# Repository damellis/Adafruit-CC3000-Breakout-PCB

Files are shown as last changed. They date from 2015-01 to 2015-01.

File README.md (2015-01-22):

Derivative of the Adafruit CC3000 Breakout PCB
==============================================
This is a derivative of the PCB for the Adafruit CC3000 WiFi Breakout. It adds an ATmega1284 and associated circuitry.

# Original Text Follows

This is the PCB for the Adafruit CC3000 WiFi Breakout
Format is EagleCAD schematic and board layout

For more details, check out the product page at

-----> http://www.adafruit.com/products/1510
-----> http://www.adafruit.com/products/1469

Adafruit invests time and resources providing this open source design, 
please support Adafruit and open-source hardware by purchasing 
products from Adafruit!

Designed by Adafruit Industries.  
Creative Commons Attribution, Share-Alike license, check license.txt for more information
All text above must be included in any redistribution

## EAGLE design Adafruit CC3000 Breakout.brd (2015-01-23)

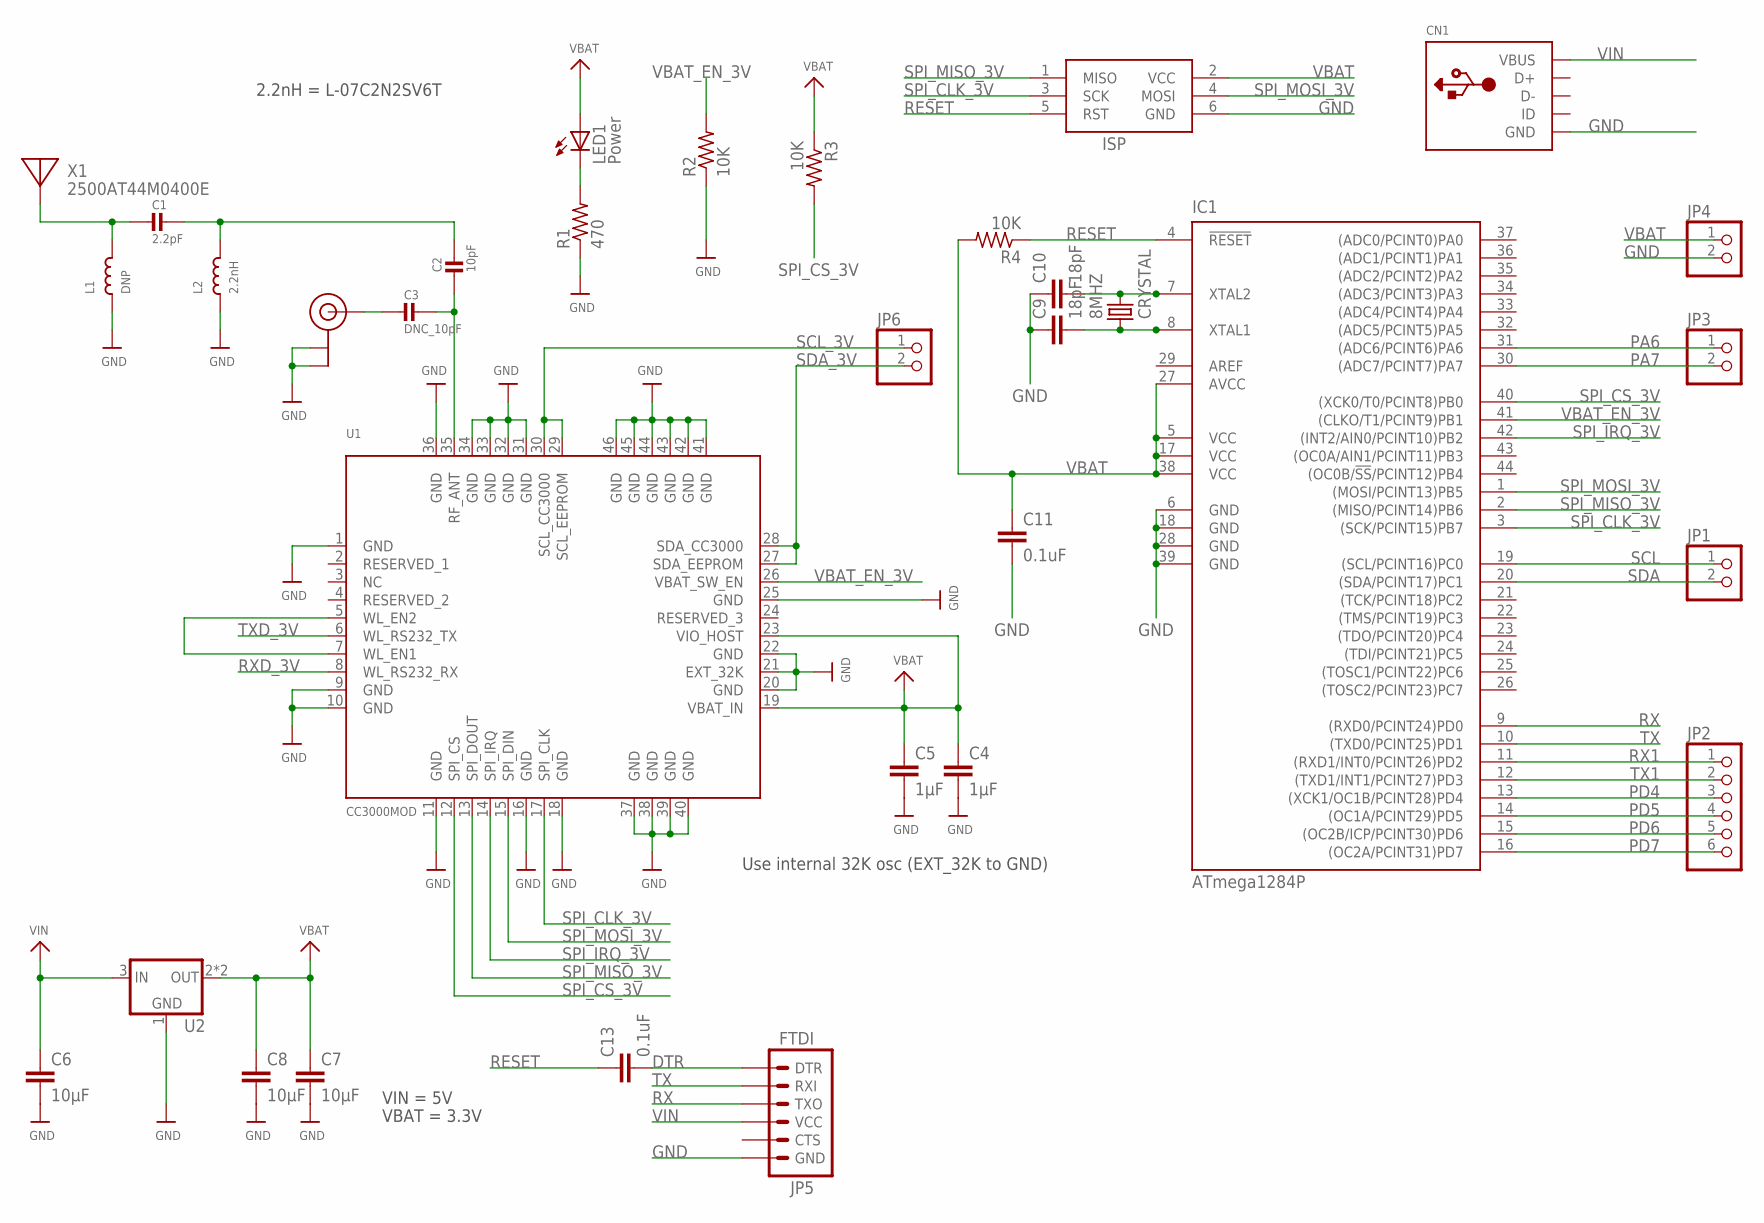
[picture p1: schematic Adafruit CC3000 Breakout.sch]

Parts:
8MHZ: CRYSTAL; 2-SMD-5X3MM
C1: 2.2pF; _0402
C2: 10pF; _0402
C3: DNC_10pF; _0402
C4, C5: 1µF; C1206
C6, C7, C8: 10µF; C1206
C9, C10: 18pF; C1206
C11, C13: 0.1uF; C1206
CN1: USBPWR; USB-MINIB-POWER
IC1: ATmega1284P; TQFP44
ISP: AVRISP-6; AVRISP
JP1, JP3, JP4, JP6: PINHD-1X2; 1X02
JP2: PINHD-1X6; 1X06
JP5: FTDI; 1X06
L1: DNP; _0402
L2: 2.2nH; _0402
LED1: Power; 1206
R1: 470; R1206
R2, R3, R4: 10K; R1206
U1: CC3000MOD
U2: VREG_SOT223; SOT223-R
U$35: U.FL
X1: 2500AT44M0400E; ANT_2500AT44M0400

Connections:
AREF: IC1.29 (AREF)
DTR: C13.2, JP5.DTR
GND: C4.2, C5.2, C6.2, C7.2, C8.2, C9.1, C10.1, C11.2, CN1.GND, IC1.6 (GND), IC1.18 (GND), IC1.28 (GND), IC1.39 (GND), ISP.6 (GND), JP4.2, JP5.GND, L1.1, L2.1, R1.1, R2.1, U1.1 (GND), U1.9 (GND), U1.10 (GND), U1.11 (GND), U1.16 (GND), U1.18 (GND), U1.20 (GND), U1.21 (EXT_32K), U1.22 (GND), U1.25 (GND), U1.31 (GND), U1.32 (GND), U1.33 (GND), U1.34 (GND), U1.36 (GND), U1.37 (GND), U1.38 (GND), U1.39 (GND), U1.40 (GND), U1.41 (GND), U1.42 (GND), U1.43 (GND), U1.44 (GND), U1.45 (GND), U1.46 (GND), U2.1 (GND), U$35.P$1 (GND), U$35.P$2 (GND)
unnamed: C1.2, L1.2, X1.FEED
unnamed: C1.1, C2.1, L2.2
unnamed: C3.2, U$35.P$3 (SIGNAL)
unnamed: C2.2, C3.1, U1.35 (RF_ANT)
unnamed: U1.5 (WL_EN2), U1.7 (WL_EN1)
unnamed: LED1.C, R1.2
unnamed: 8MHZ.P$2 (2), C10.2, IC1.7 (XTAL2)
unnamed: 8MHZ.P$1 (1), C9.2, IC1.8 (XTAL1)
PA6: IC1.31 ((ADC6/PCINT6)PA6), JP3.1
PA7: IC1.30 ((ADC7/PCINT7)PA7), JP3.2
PD4: IC1.13 ((XCK1/OC1B/PCINT28)PD4), JP2.3
PD5: IC1.14 ((OC1A/PCINT29)PD5), JP2.4
PD6: IC1.15 ((OC2B/ICP/PCINT30)PD6), JP2.5
PD7: IC1.16 ((OC2A/PCINT31)PD7), JP2.6
RESET: C13.1, IC1.4 (!RESET), ISP.5 (RST), R4.1
RX: IC1.9 ((RXD0/PCINT24)PD0), JP5.TXO
RX1: IC1.11 ((RXD1/INT0/PCINT26)PD2), JP2.1
RXD_3V: U1.8 (WL_RS232_RX)
SCL: IC1.19 ((SCL/PCINT16)PC0), JP1.1
SCL_3V: JP6.1, U1.29 (SCL_EEPROM), U1.30 (SCL_CC3000)
SDA: IC1.20 ((SDA/PCINT17)PC1), JP1.2
SDA_3V: JP6.2, U1.27 (SDA_EEPROM), U1.28 (SDA_CC3000)
SPI_CLK_3V: IC1.3 ((SCK/PCINT15)PB7), ISP.3 (SCK), U1.17 (SPI_CLK)
SPI_CS_3V: IC1.40 ((XCK0/T0/PCINT8)PB0), R3.2, U1.12 (SPI_CS)
SPI_IRQ_3V: IC1.42 ((INT2/AIN0/PCINT10)PB2), U1.14 (SPI_IRQ)
SPI_MISO_3V: IC1.2 ((MISO/PCINT14)PB6), ISP.1 (MISO), U1.13 (SPI_DOUT)
SPI_MOSI_3V: IC1.1 ((MOSI/PCINT13)PB5), ISP.4 (MOSI), U1.15 (SPI_DIN)
TX: IC1.10 ((TXD0/PCINT25)PD1), JP5.RXI
TX1: IC1.12 ((TXD1/INT1/PCINT27)PD3), JP2.2
TXD_3V: U1.6 (WL_RS232_TX)
VBAT: C4.1, C5.1, C7.1, C8.1, C11.1, IC1.5 (VCC), IC1.17 (VCC), IC1.27 (AVCC), IC1.38 (VCC), ISP.2 (VCC), JP4.1, LED1.A, R3.1, R4.2, U1.19 (VBAT_IN), U1.23 (VIO_HOST), U2.2 (OUT), U2.4 (OUT)
VBAT_EN_3V: IC1.41 ((CLKO/T1/PCINT9)PB1), R2.2, U1.26 (VBAT_SW_EN)
VIN: C6.1, CN1.VBUS, JP5.VCC, U2.3 (IN)

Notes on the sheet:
Use internal 32K osc (EXT_32K to GND)
VIN = 5V
VBAT = 3.3V
2.2nH = L-07C2N2SV6T

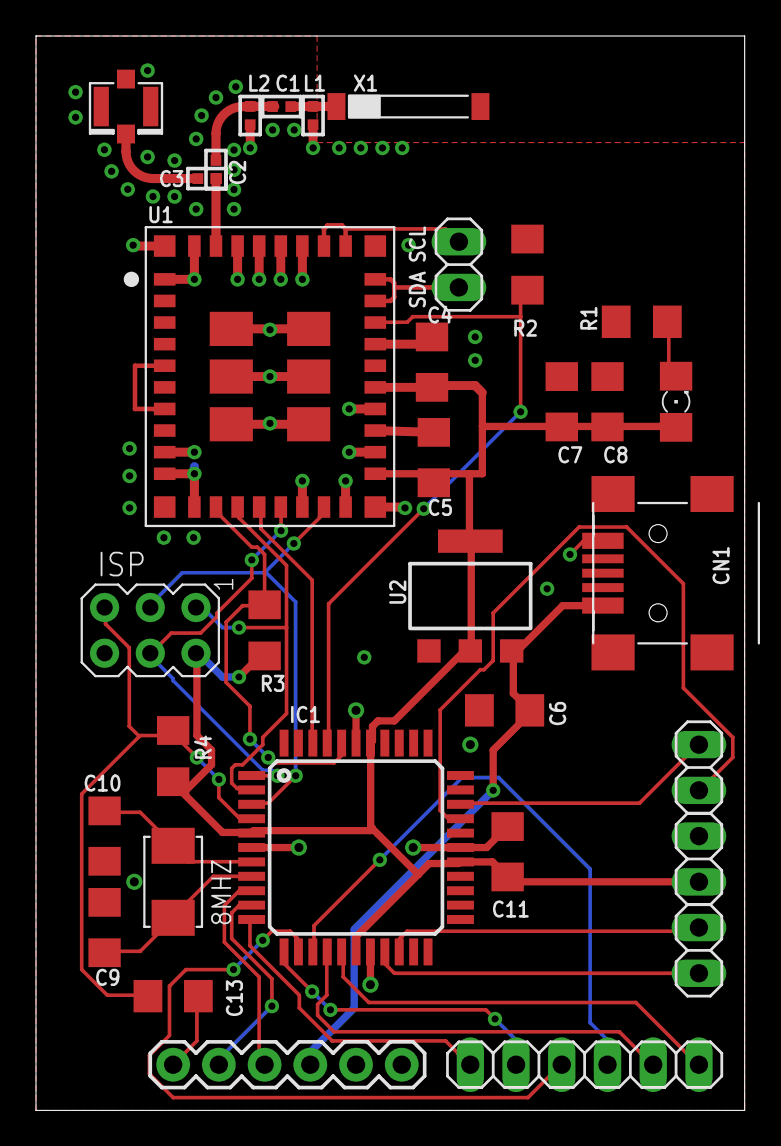
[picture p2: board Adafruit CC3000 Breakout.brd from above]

Board: 2 copper layers, 39.4 x 59.7 mm, 33 parts (0 on the bottom side), 33 nets.

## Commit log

2015-01-21 Merge with net widget.
    https://github.com/damellis/netwidget
    [Adafruit CC3000 Breakout.brd, Adafruit CC3000 Breakout.sch]
2015-01-21 Smoosh everything together.
    Not routed yet, and some passives are 1206 and others are 0805.
    [Adafruit CC3000 Breakout.brd, Adafruit CC3000 Breakout.sch]
2015-01-21 Remove CC3000 RX and TX debug header.
    And mounting holes.
    [Adafruit CC3000 Breakout.brd, Adafruit CC3000 Breakout.sch]
2015-01-22 Replace passives (w/ 1206), re-layout components.
    Also, change pinouts on the ATmega1284P to match the Wicked Devices
    Wildfire prototyping board. Remove rounded corners.
    [Adafruit CC3000 Breakout.brd, Adafruit CC3000 Breakout.sch]
2015-01-22 Route board.
    [Adafruit CC3000 Breakout.brd]
2015-01-22 Breakout some microcontroller pins.
    Partly un-route the board.
    [Adafruit CC3000 Breakout.brd, Adafruit CC3000 Breakout.sch]
2015-01-22 Breakout power and ground. Align to inch grid.
    [Adafruit CC3000 Breakout.brd, Adafruit CC3000 Breakout.sch]
2015-01-22 Put CC3000 I2C pins on 0.1" pins.
    Instead of test points.
    [Adafruit CC3000 Breakout.brd, Adafruit CC3000 Breakout.sch]
2015-01-22 Make some ground via's.
    In the hopes it will help with routing.
    [Adafruit CC3000 Breakout.brd]
2015-01-22 Add restrict under CC3000 for routing.
    [Adafruit CC3000 Breakout.brd]
2015-01-23 Silk screen (and name some traces).
    [Adafruit CC3000 Breakout.brd, Adafruit CC3000 Breakout.sch]
2015-01-23 Tweak a via's position.
    [Adafruit CC3000 Breakout.brd]
2015-01-23 Add date and generate gerbers.
    [Adafruit CC3000 Breakout.brd]

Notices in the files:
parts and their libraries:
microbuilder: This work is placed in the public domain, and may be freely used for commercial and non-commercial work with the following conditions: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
